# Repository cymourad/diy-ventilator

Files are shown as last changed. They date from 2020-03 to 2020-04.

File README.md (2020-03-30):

# DIY-Ventilator
This is an attempt to make a simple DIY Ventilator using:
1. Standard mask, tube, and 2 Y-pieces;
2. 3D printer and filament;
3. Arduino board, BLE module and humidity sensor;
4. Choice of battery that outputs ## V and has capacity of ##;
5. Brushless DC motor blower;
6. Oxygen tank, flow meter and regulator; and
7. HEPA filters

## Files in the Respistory
This respository contains 7 sub-repositories:
1. **app**: This respository hosts the source code of two identical mobile applications (IOS and Android) to control and monitor the ventilator.
2. **fw** (FirmWare): This directory contains the firmware code that would run on the Arduino board to control the ventilator.
3. **mech** (Mechanical): This directory contains the CAD files used to 3D print the custom parts of the ventilator, and the readily-avialble parts we bought.
4. **prototypes**: This directory is a sandbox for the team to share their early-stage design ideas, sketches, prototypes, etc.
5. **resources**: This directory contains all the references we used, as well as datasheets and manuals for readily-available parts that we used to build the ventilator.
6. **tests**: This directory includes User Acceptance Tests (UAT) to run on the assembled ventilator before the aptient uses it. It also includes tests to be run by the team as we develop the ventilator to make sure our changes are moving in the right direction.
7. **tutorials**: This directory includes the tutroials that the app will feature to educate operators on the assembly and use of the ventilator.

## Team
I am by no means working on this project alone. The team who is contributing to this project with different capacities, according to their expertise, is comprised of:
* Abanoub Rizk
* Abanoub Slaib 
* Bishoy Mikhail
* Hani Zaki
* Marina Saad
* Nazmy Markos
* Nicolas Mourad
* Youhanna Iskander
* Youssed Zaki

## WARNING
**This project is by no means complete or thoroughly tested yet!**

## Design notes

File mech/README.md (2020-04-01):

# DIY-Ventialtor Mechanical Parts
This directory contains the CAD files of the parts that must be 3D-printed to make the ventilator, as well as the readily-available parts we used (and potential equivalent parts) to make the design below.
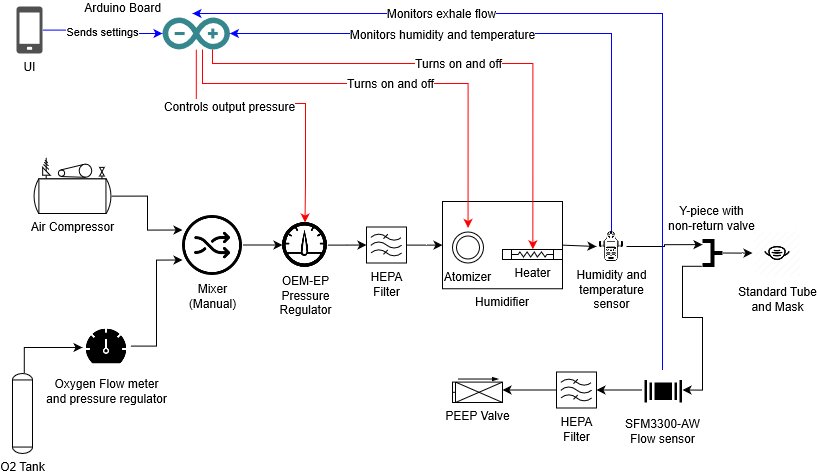
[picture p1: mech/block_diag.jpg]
Ventilator Block Diagram Design Ventilator Block Diagram


## CAD Parts

### Humidifier Chamber
* This part takes the pressure regulator output as its input and outputs to the Y-piece that connects to the tube going to the patient.
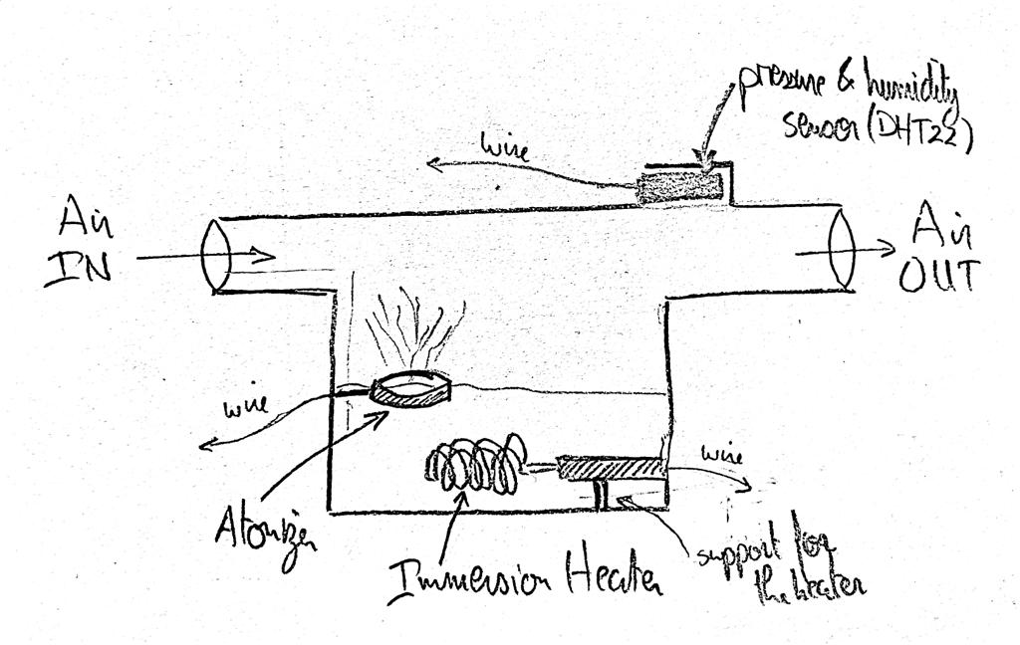
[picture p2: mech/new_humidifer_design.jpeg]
humidifer design Humidifer Design

* TODO add special instructions to print (material, orientation, printer settings )
* TODO add a picture of it printed

### HEPA Filter
* this parts makes the air pass through a HEPA filter to disinfect it
* TODO add special instructions to print (material, orientation, printer settings )
* TODO add a picture of it printed

## Readily Available Parts

### Arduino UNO Baord
* This is the brain if the ventilator, it controls the outputs and makes sense of the inputs. This is our controller.
* Can be purchased from [here](https://www.amazon.ca/ARDUINO-A000066-Uno-DIP-1-5/dp/B008GRTSV6).

### Arduino HM-10 Bluetooth Module
* This module connects to our microcontroller and it lets the user send the desired settings over bluetooth from their phone.
* Can be pruchased from[here](https://www.amazon.com/DSD-TECH-Bluetooth-iBeacon-Arduino/dp/B06WGZB2N4)

### Air Compressor
* This part is respoinsible for generating our airflow at 50 psi for belnding.
* Can be prucahsed [here](https://www.healthproductsforyou.com/p-precision-medical-easyair-pressure-compressor.html).

### Oxygen tank and oxygen regulator
* This is the source of Oxygen to regulate FiO2 higer than 21%. The regulator controls the pressure going out of the compressed oxygen tank to (typically) 3-5 bar. While
* These parts can be purchased or rented. They are standard parts so any combination should work. An example of the flow meter and regulator can be found [here](https://www.emrn.ca/en/respiratory/oxygen-regulators/o-two-oxygen-regulator-0-25-lpm-all-brass.html).

### Oxygen/Air Blender
* Regulates the pressures of the air and oxygen and lets the user control their flows to achieve desired FiO2.
* Can be purchased [here](https://www.tristatebiomedical.com/store/p160/Maxtec_MaxFLO2_Mini_Air_%2F_Oxygen_Mixer.html).

### HEPA Paper
* This piece disinfects the air before going into the machine and eventually to the patient.
* Can be purchased [here](https://www.cpap.com/productSearch#::::HEPA%20filters).

### Pressure Reducing Valve
* This piece takes the pressure down from 50 psi to 50 cmH2O for the pressure regulator to be able to reduce it to the desired range (will go down from 50 psi to 2 psi).
* Can be purchase at [here](https://www.pneumaticplus.com/pneumaticplus-ppr2-n02bg-miniature-air-pressure-regulator-1-4-npt-with-embedded-gauge-bracket/).

### Parker OEM-EP (Miniature Electronic Pressure Controller)
* This device takes any pressure greter than 40 cmH2O (can be variable pressure) and outputs a regulated pressure (10% - 100% of its input pressure.)
* Its data sheet can be found [here](https://www.parker.com/Literature/Precision%20Fluidics/Electronic%20Pressure%20Controllers/PPF_Pressure_Control_Catalog.pdf).

### Atomizer
* This small device floats on a water surface and atomizes tiny water dropplets to the air above to increase its humidity.
* Can be purchased [here](https://www.amazon.com/Gikfun-Ultrasonic-Ceramics-Sealing-Diffuser/dp/B075CHT2HY).

### Immersion heater
* Immersion heaters are commonly used to heat up water or coffe in a glass. So, we can use one to heat up the water and thus heat up to the air to reach 50 degress Celsius.
* Can be purchased [here](https://www.bedbathandbeyond.ca/store/product/portable-immersion-heater/1011091717?product_id=11091717CA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).

### Pressure and humidity sensor
* This device outputs the current temperature and relative humidity to the Arduino.
* Can be purchased [here](https://www.amazon.com/AZDelivery-Digital-Temperature-Humidity-Raspberry/dp/B07F86WXR7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).

### Y-piece with non-return valve
* This piece conncects the air flow coming from the machine with the tube, and lets the air exhaled back from the patient exit from a third outlet.
* Can be purchased [here](https://www.biodex.com/nuclear-medicine/products/lung-ventilation-systems/xenon-disposables/y-connector).

### Proximal Flow Sensor (Sensirion SFM3300-AW)
* This device reads the current flow rate. Two will be used to monitor the exhaled tidal volume.
* Its data sheet can be found [here](https://www.sensirion.com/fileadmin/user_upload/customers/sensirion/Dokumente/5_Mass_Flow_Meters/Datasheets/Sensirion_Mass_Flow_Meters_SFM3300_Datasheet.pdf).

### PEEP valve
* This device connects to the last Y-piece on the exhale end before the proximal flow sensor.
* can be purchase [here](https://www.emsstuff.com/disposable-universal-peep-valve/).

### Tube and Mask
* These are standard tube and mask to connect to the patient.
* An example tube can be found [here](https://cpapmachinescanada.ca/products/resmed-standard-tube-6-feet-and-9-feet?variant=49938448967) and masks are determined [based on the patient's features](https://www.oxygenconcentratorstore.com/cpap-mask-sizing-guide-and-maintenance/#).

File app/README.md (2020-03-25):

# DIY-Ventilator
This repositry hosts two sub-repositories that feature the code of two identical mobile applications: an IOS app and an Android.
The app conncets to the Arduino controlling the ventilator and features two main tabs:
1. Settings
2. Tutorials

As the machines is designed to be modualr, the user must first indicate in the settings which parts are connected:
* BPAP (base/default)
* Oxygen supply (to be connected immediately to the output of the ventilator)
* Humidifier (to be connected to the output of the ventilator before the tube)

Then, the user must indicate which mode they want to operate in (the tutorials give the user guidance on which mode to choose based on the conditions of the patient):
* Bi-PAP (patient is unconscious, cannot breathe on their own)
* C-PAP (patient is conscious but having difficulty breathing)
* Assist (difficult is back to normal brething but sometimes skips a breath)

The user must also enter the height, weight, age and sex of the patient for the machine to calculate some parameters. Moreover, the user can choose to have more manual control and enter a set pressure for the C-PAP mode or set low and high pressures (PIP and PEEP) for the Bi-PAP mode.

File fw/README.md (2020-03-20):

# DIY-Ventilator Firmware
This respository contains the firmware that runs on the Arduino board to control the ventilator and connect to the app.

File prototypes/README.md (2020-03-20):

# DIY-Ventilator Prototypes
This is a sandbox for the team to share our ideas, early designs and sketches.

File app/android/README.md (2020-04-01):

# DIY-Ventilator Android App
The app conncets to the Arduino controlling the ventilator and features two main tabs:
1. Settings
2. Tutorials

The respository that contains the code for the IOS app can be found [here](https://github.com/bishoymikhail/DIY-Ventilator-Android-Application).

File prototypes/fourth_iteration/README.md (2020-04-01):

# DIY-Ventilator 4th Iteration
I video conferenced Nazmy today for around 7 hours. This man wrecked almost everything. It's late. There is so much to document. I'll capture the most important things as much as I can.

## Parker pressure regulator
We forgot to check its flow range. Some max out at 20 L/min, which is pretty low, so might need to find different models and a different part all togheter. Also, because it scales it input pressure 10% - 100%, we must provide it with 40-50 cmH2O to get our desired range. So, we gotta do some serious pressure reduction to go from 50 psi (~3515.35 cmH2O) to 50 cmH2O (~70x). We might need to do this reduction on two stages. But good news is: this is a fixed reduction so we can use mechanical valves with no control and they should be cheaper

## Tidal volume
A call with an anathtiliologist (def spelled that wrong) informed us that for COVID-19, the patient would need a Vt of 6 mL/kg (yieldning and avg Vt of 0.426 L). Aslo, avg person is around 71 kgs. So, to caculate our flow rate (Q) range:
> Q [L/min] = Vt / (inhale period)

## Oxygen blending
Nazmy made it clear that it is better to blend at a high pressure. It also became clear after some research that most belnders (like [this Maxtec one](https://www.tristatebiomedical.com/store/p160/Maxtec_MaxFLO2_Mini_Air_%2F_Oxygen_Mixer.html)) are designed for the 40-50 psi range, which is conviently the pressure coming out of an Oxygen tank.
Omitting much discussion, we decided that using a ready made blender and an air compressor might be the sweet spot between precision and safety vs cost. The final concern we had was running this compressor on a battery for 3 hours in case power goes out. Nazmy is looking into this tonight.
Meanwhile, Hani was looking into using the venturi principle instead on a standard compressor and belnder. We will design the venturi and some seious control logic with some regulaor solenoids. This design would be so much cheaper (but maybe harder for an average person to assemble). Main problem with this design is it must supply a minimum FiO2 of 40%.
*Update*: Nazmy found [this medical grade compressor](https://www.healthproductsforyou.com/p-precision-medical-easyair-pressure-compressor.html). It should get the job (50 psi , min flow of 13 lpm, and great safety) down and it runs on only 0.2 hp (so we can run it on a battery for 3 hours).

## Humidifier
Also giving the summary of long dicussions here. Using a simple atomizer will not give us enough control over humidity. We generally want 55% humidity. I looked into HMEs because they seem easy and cheap.
*Update*: Even tho HMEs seem like an easy fix, they can only last for a few hours. It turns out they are usually used in surgeries. I think we can build our humidifer and test it. If it does not work as expected, we can have HMEs as plan B and pray the users will have access to them.

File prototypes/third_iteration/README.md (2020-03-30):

# DIY-Ventilator 3rd Iteration
We met again on March 28, 2020. 

## Humidifier
After studying humidifiers for the day, we learnt the following:
* there are two types of humidifiers: atomizers and heaters. Atomizers keep the temperature of the water the same and simply atomizes some water int dropplets in the air. A heater heats up the water till it evaporizes.
* temperature of air drops significantly across the tube. So industry either uses a tube that has a heater in it, or regulates the air temperature to 50 degress Celsius so that by the time it travels the standard length tube it arrives to the patient at 37 degress Celsius.

Upon some discussions around the trade-offs between accuracy, cost, availabilty of material and ease of making, we arrived to the following design.
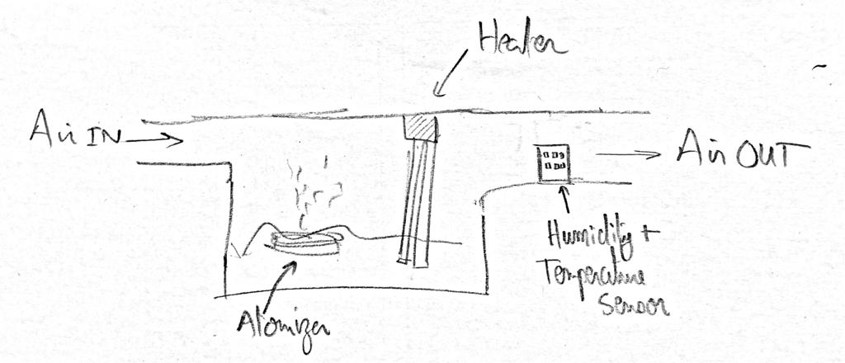
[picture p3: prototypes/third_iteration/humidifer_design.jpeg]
humidifer design Humidifer Design


An atomizer (like [this one](https://www.amazon.com/Gikfun-Ultrasonic-Ceramics-Sealing-Diffuser/dp/B075CHT2HY)) is primairly responsible for controlling the humidity level. An immersion heater (like [this one](https://www.walmart.ca/en/ip/Portable-Safe-Car-12V-24V-Immersion-Water-Heater-Auto-Electric-Tea-Coffee-Water-Heater/5EUK9APPV4YD)) is primairly responsible for heating the air to 50 degrees Celsius and it also heats up the water so it will affect the humidity slightly. A humidity and temperature sensor (like the [DHT22](https://www.amazon.com/AZDelivery-Digital-Temperature-Humidity-Raspberry/dp/B07F86WXR7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)) will provide feedback to adjust both the temperature and humidity.

## Blending Oxygen and Air
Upon his research, John generated the table below to adjust the flow rate coming out of the fan blower and the flow coming out of an oxygen tank to achieve the desired FiO2.
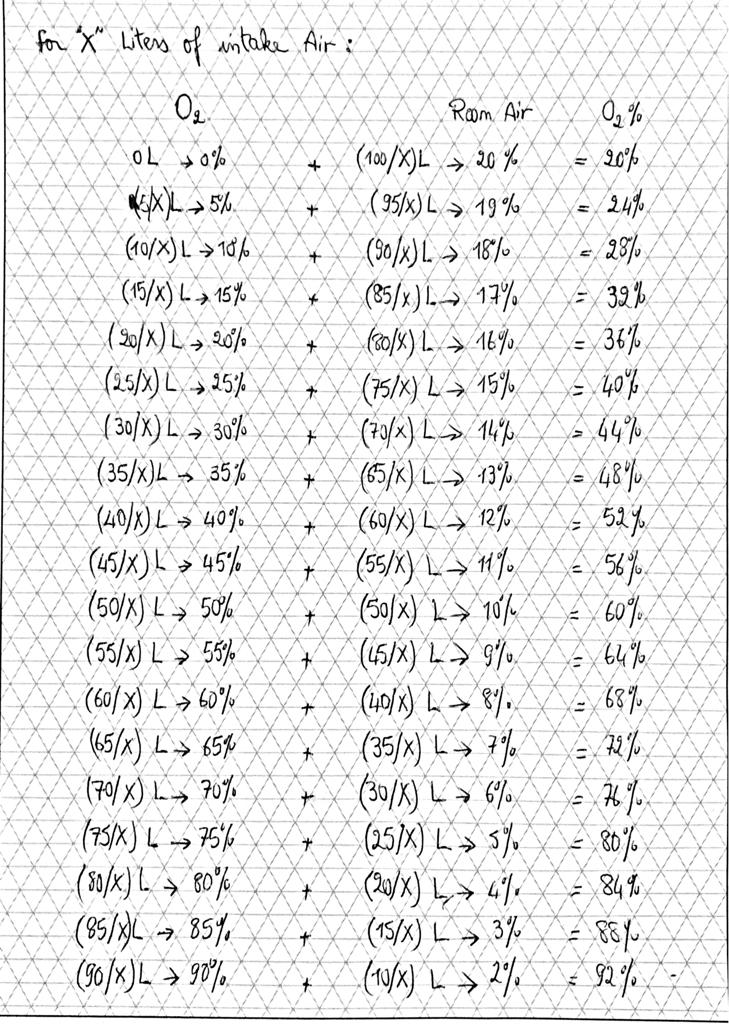
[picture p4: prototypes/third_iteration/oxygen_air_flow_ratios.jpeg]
Oxygen Blending Ratios Table


To simplify the design, the UI can tell the user to adjust the oxygen flow and pressure regulator manually (like [this one](https://www.ocelco.com/store/pc/Regulator-for-Oxygen-Flowmeter-with-1-2-15-LPM-CGA-540-Nut-and-Nipple-Inlet-Connection-p6442.htm)). These regulators and flow meters usually come with a rented oxygen tank, and they follow standards so any tank and regulator that a user chooses should work with our design. As for the flow rate of the air, it can be controlled through the speed of the fan blower. 
The control software would know what speed the fan is rotating at and this how much airflow it's generating. Thus, if we put a proximal flow sensor to meausure the combined air and oxygen flow after the y-piece, we would know the oxygen's flow rate (by substracting the fan's flow rate from the sensor's reading). Then, we can decrease or increase the speed of the fan to compnesate for any inacuracy and deliver a steady flow rate.
The design would look as follows:
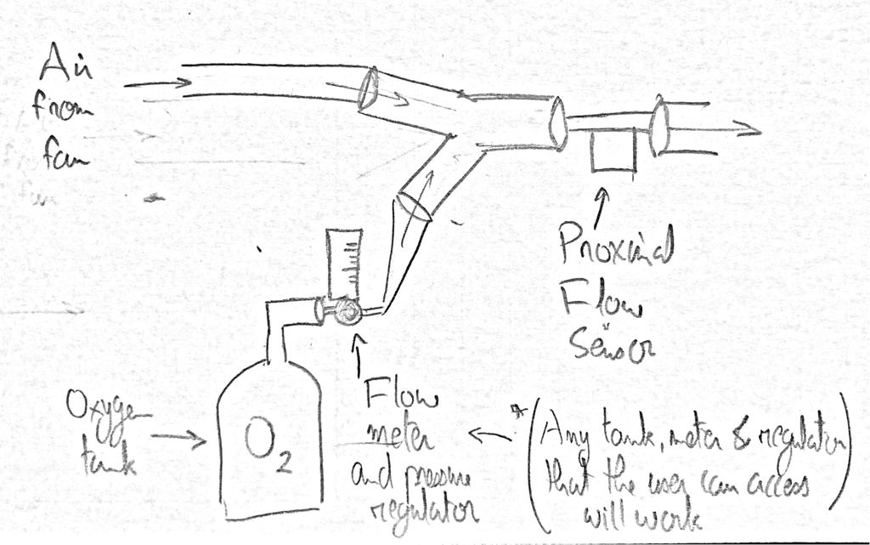
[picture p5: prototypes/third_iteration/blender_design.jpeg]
Blender Design


~~On a seperate note, if we use a delta fan blower (like [this one](https://www.digikey.ca/product-detail/en/delta-electronics/ASB0312HA-AF00/603-1723-ND/3444171) for example), we can use its [PWM signal](https://www.delta-fan.com/NewsDetail.aspx?NID=71) to control its speed and thus its flow rate. This would also mean that we would have to design our own shell to boost the fan's pressure.~~

## Pressure Control
Upon inspecting the [datasheet of the pressure regulator](https://www.parker.com/Literature/Precision%20Fluidics/Electronic%20Pressure%20Controllers/PPF_Pressure_Control_Catalog.pdf), we learnt that it can output 10-100% of the pressure that is given to it. In other words, we must provide it with a minimum of 40 cmH2O to be able to get the full range of desired pressures (5-40 cmH2O). This discovery lauched us on a quest of fluid mechanics search, we looked into using a diffuser to amplify the pressure of the fan, and looked into the equations that would help us design it. Then, we thought to find fan blowers that would simply give us the desired perssure, and we found this very reasonbaly-priced [burshless DC motor blower](https://www.alibaba.com/product-detail/12-24V-brushless-dc-motor-blower_60657146534.html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) that would deliver our desired pressure and flow rate.

This motor blower comes with a shell to amplify pressures (just like the leaf-blowers). The realtion between the airflow and the pressure it provides is shown in the following graph.
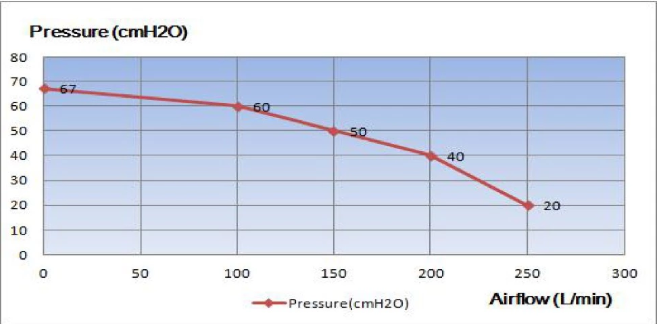
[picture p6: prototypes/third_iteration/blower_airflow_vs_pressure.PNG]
Blower's Airflow vs Pressure
.

This graph means that we can deliver up to 200 L/min and still get the required 40 cmH2O. We only to deliver 60-120 L/min, so we can definetely use this fan.

The next challenge we faced is that oxygen tanks usually deliver pressure between 3 and 5 bars, which is 3000 to 5000 cmH2O. So, tommorw, we need to find a way to bring this pressure down signiicatly to the 40 cmH2O range that the blower is gonna provide to be able to blend them with the flow rate rations in the table that John generated.

## Tidal Volume (Vt)
Our ventilator will be monitoring the exhaled tidal volme and will give the operator an alert if the user is exhaling substantially more or less volume (let's say a +/- 10% window). The standard equation to calculate tidal volume for adults is calculated based on the patient's weight (in kgs) as follows: 
> Vt = 7 mL/kg

Thus, the operator will input the patient's weight into the UI and the app will calculate the desired Vt and send it to the Arduino. If the proximal sensor indicates that the exhaled Vt is more than 10% of this reference value, or less than 10% of it, it will gove the operator an alert.

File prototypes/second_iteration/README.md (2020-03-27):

# DIY-Ventilator 2nd Iteration

Late at night on March 24, 2020, Hani, John and I had a conversation about the design. We came up with a few improvements:
* globe or butterfly valves seem like good options to control the pressure of the air and the FiO2 (they are rotary so they allow fast control, and they allow flow regulations (not just one/off))
* remembering to go back to the basics when it comes to controls, we need to now the tidal volume and the respiratory rate. Based on those 2 pieces of information we will know the volume of air that the blower must deliver. We also need to derive how long an inhale takes and how long an exhale takes (exhale takes longer) to know how often to change the pressure in Bi-PAP mode
* for Bi-PAP mode, instead of having one channel for the air and keep switching the position of the valve to change the pressure for PIP and PEEP, have a air blown by the fam split throug a y-piece that has two valves connected to its two outlets and a switch that controls which outlet the air goes to. This way, the regulating valves will only need to change their positions when settings chnage, and the switch will do the heavy lifting. This Y-piece then connect to another Y-piece to connect to the patient's tube. This would look like something similar to the picture below.
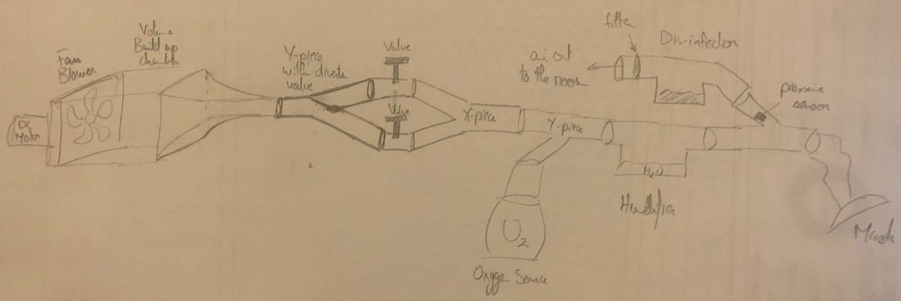
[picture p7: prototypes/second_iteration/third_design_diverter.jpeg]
third design with blower fan and 2 valves Third design with blower fan and 2 valves


Action list for our meeting on March 25, 2020:
* finalize design
* order parts and decide which parts will be designed in-house
* figure out the parameters needed to run in Bi-PAP and C-PAP modes (what we should ask the user to provide) and how to translate them into:
1. speed of fan blower, 
2. position of pressure valves, and 
3. delays when diverting flow between PIP and PEEP.

I think the diagram below might help us with this third task.
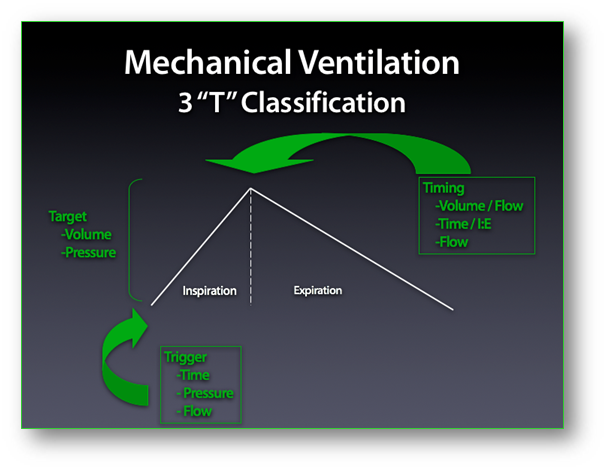
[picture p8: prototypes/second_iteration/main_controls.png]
main Bi-PAP ventilation controls Main Bi-PAP Ventilation Controls


We meet on March 25, 2020. We started by reviewing the new list of requirements one last time before changing our design and desciding what parts to buy and what parts to make. The new requirements explicitly ask for:
* the integration of a humidifier (to control humidity and air temperature), 
* the interation of an Oxygen blender (to control the FiO2),
* pressure controlled ventialtion (as opposed to volume controlled),
* A/C (Assited/Controlled breaths) modes of ventilation (a.k.a. patient-triggered vs machine-triggered ventilation), 
* monitoring of Vt (tidal volume), and
* alerts when max inhale and exhale pressures are exceeded, as well as a fail-safe method to limit the max pressure.

Those new requirements meant that the following inputs must be supplied by the user (and therefore the interface must allow the user to set them):
* PIP (Peak Inspiratory Pressure [cmH2O], 5 < PIP < 40)
* PEEP (Positive End of Exhalation Pressure [cmH2O], 4 < PEEP < 20)
* RR (Respiratory rate [breaths/minute] 4 < RR < 60)
* I:E Ratio (Ratio of Inhale to Exhale time)
* FiO2 (Perecentage of Oxygen in air [%], 20 < FiO2 < 100)
* Humidity (of air [units])
* Temperature (of air [degrees Celsius])

The machine must control:
* two pressures (PIP and PEEP),
* the intervals of switching between them,
* blending the air and Oxygen,
* humidity and temperature, and
* listening to the patient asing for a breath in patient-triggered mode.

Thus, the design we can come up with the night before seemed to satisfy the requirements. It seemed like blending should have happened before controlling the pressure and upon looking at literature it turned out that this new suggestion was true.

At this point, it was time to browse the internet to find:
* low pressure regulators (a.k.a. low pressure valves) --> for 0 to 50 cmH20 (which is 0 to 0.5 psi)
* flow meters
* oxygen blender
* fan blower
* simple humidifier

This 3 hour component search was eye-opening to say the least.
* Oxygen belnders turned out to cost somewhere between $1,000 and $2,000. Upon some literature reading, we came to the conclusion that the sweet spot of most cost effective and easy to build blender can be achieved if we just buy a flow regulator to hook up to the oxygen source, and buy a flow meter. Then, we connect those Oxygen source and the air coming out of the fan blower to a mixing chamber that we design and 3D print. When the user requests a certain FiO2, we ask them to turn the manual knob of the Oxygen flow regulator, and use the flow meter to regulate the speed of the fan blower to produce a flow of air that summed with the flow of Oxygen would result in the desired combination.
* Even though high pressure regulator are so widely available, it is considerbaly more dificult to find a low pressure regulator (for the range we are seeking to control). The next best option is a needle valve to regulate the flow (and use a pressure sensor and a feedback loop to adjust the valve to achieve desire pressure); but needle valves turned out to be not that much better in terms of avilability. Giving in to the $150 price range, we found that Parker sells a low pressure regulator that hits our desired pressure range with high accuracy and can switch between pressures fairly quickly. Thus, we decided that if $150 could give us fast switching between pressures (thus eliminatin the need for a diverter and two different channels) and precise pressure regulation (eliminating the need for two needle valves, two pressure sensors and two feedback control loops), a Parker pressure regulator (like [this one](https://www.parker.com/Literature/Precision%20Fluidics/Electronic%20Pressure%20Controllers/PPF_Pressure_Control_Catalog.pdf)) would be worth the price (especially given the time and resource constraints).
* We need a flow sensor to regulate the oxygen/air blending, and we need another one to monitor the actualy tidal valume from the exhale. Water flow meters/sensors are so widely avaibale. But, a lot of them are mechanical and thus useless to out controller, and the ones that are electronic are not suitable for air flow measurements. Instead, the type of flow sensor we are looking for is called a prximal flow sensor. An avergae prximal sensor (like [this one](https://www.sensirion.com/en/flow-sensors/proximal-flow-sensors/)) would cose around $300. 
* These parts are not usually found on Amazon or E-Bay. They even sometimes ask you to request a quote.

In light of these decisions, the final design has been modified to look as follows:
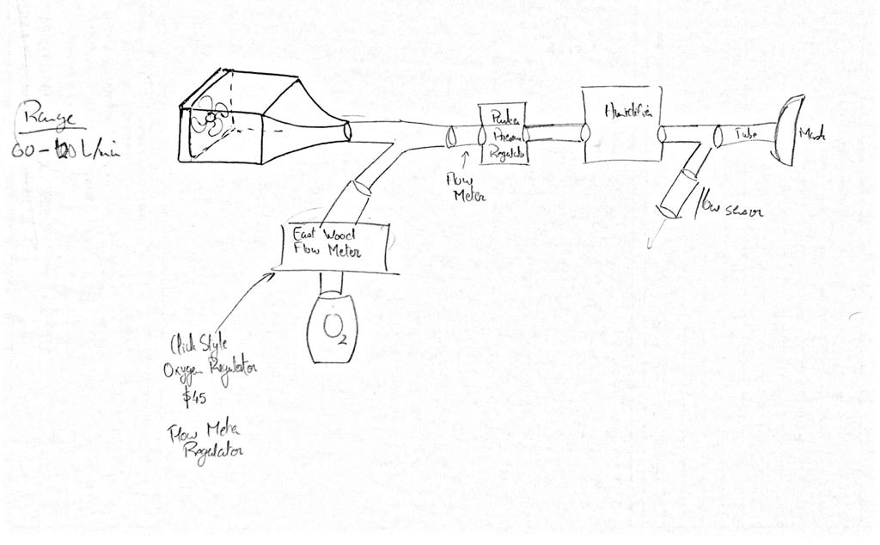
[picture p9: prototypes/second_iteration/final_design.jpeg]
final design Final Design


Final action plan:
* change interface (app) to prompt for the fina list of inputs,
* look at the data sheets of the parts we found and figure out who they will be integrated with the contoller,
* design the parts that will connect the bought parts together, and
* write the control algorithm.

### Humidifer
Arduino provides a few humidity and temperature sensors like the [DHT22](https://www.tutorialspoint.com/arduino/arduino_humidity_sensor.htm) which measures relative humidity and temperature. It as cheap as [$5](https://www.amazon.com/AZDelivery-Digital-Temperature-Humidity-Raspberry/dp/B07F86WXR7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) and it prvides reasonable accuracy for the application.
We could use one of those [mist makers](https://www.aliexpress.com/item/32986565997.html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) to vaporize water and increase humidity but if we do so we won't be able to control the temperature.
To heat the water, we can use a [commercial immersion heater](https://www.aliexpress.com/item/4000311044016.html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) and do some surgey one the wires to turn it ON/OFF with the Arduino.

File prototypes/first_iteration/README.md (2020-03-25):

# DIY-Ventialtor 1st Iteration
On March 21, 2020, Hany Zaki, Youssef Zaki, Youhanna Iskander, Nicolas Mourad and I dicussed a few ideas for a first design.

## Basic ventilator types
Hany explained to us that the early ventilators he worked with had three main modes which relate to the patient's condition:
1. **Bi-PAP**: patient is unconcscious and in very difficult condition, patiet cannot breathe on their own, Bi-PAP must artifically inhale (at Inspiratory Pressure, PIP) and exhale (at Expiratory Pressure, PEEP) at a set respiratory rate for the patient who exerts no resistance on the machine. This pressured air is often mixed with a hihger concentration of oxyen.
2. **C-PAP**: when the patient gets a little better and they become conscious and in control of their respiratory system again, the ventilator supplies constant pressured air (often mixed with oxygen).
3. **Patient-triggered**: the patient can fully brethe on thier own anf they are about to get weaned off the ventialtor but they sometimes miss a breath and/or they need a supply of oxygen, ventilator supplies pressured air at a low pressure (close to 4 cmH2O) and senses when the patient skips a breath, in which case it supplues a single IPAP cycle at the patient's average respiratory rate with their average tidal volume.

## Design principles
Common themes that we decided to kee through our design cycles were:
* break it to modules: break ventilator down to smaller standalone pieces (in case people do not need some functionalty or cannot find certain components AND for ease of testing)
* do not re-invent the wheel: use as many readily-available parts and technology as possible to increase reliability and to have online support community that can help with development and testing
* keep it simple: do not include functionality, features, or components that are not needed for most users (to minimize modes of failures and for ease of assembly and use)

## First design
We quickly came up with this first design, that was dismissed after for being a tad too complex.
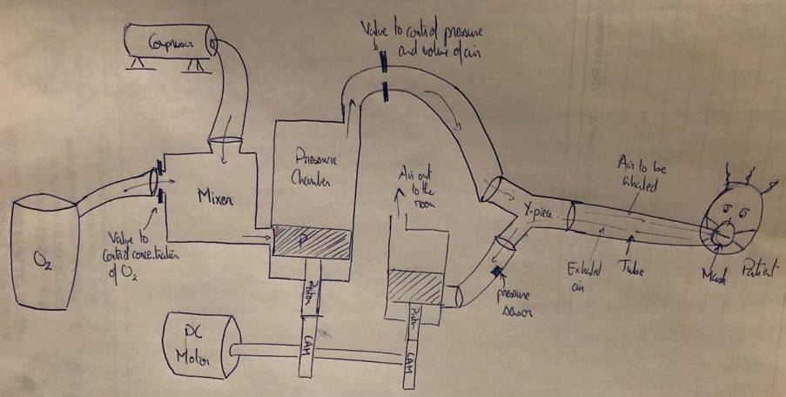
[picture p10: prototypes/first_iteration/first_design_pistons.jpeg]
first design with pistons, cam-shaft, mixer chamber, and two pressure chambers First Design with pistons and cam-shafts and mixer

Starting from the right, a mixing chamber takes compressed air from a compressor and an oxyen tank or an oxyen concentrator. The FiO2 is controlled with a valve that connects the oxygen source to this mixing chamber.
Then, the air goes into a pressure chamber. A DC motor rotates a shaft and a cam that pushes a piston to compress the air in the pressure chamber and pushes it out to a valve that controls the pressure (and volume) of the air going out to the patient. Then, the valvev connects to a Y-piece that connects on one side to the tube and mask going out to the patient, and on the other side to a tube that contains a pressure sensor and connects to a pressure chamber that sucks the air back to simulate an exhale. The second pressure chamber is operated by the same DC motor and shat but a different sized cam.

## Second design
We examined the design and found some repition (compressing the air twice first with the compressor then with the piston, using two pressure chambers for inhale and exhale). Also, since the cam had a set size, it was difficult to provide two different pressures from one pressure chamber (PIP and PEEP). So, we decided to come up with another idea and compare the two.
We decided to use a blower fan and a valve to compress the air instead of the pressure chambers. This simplified our desing quite a bit as seen in the sketch below.
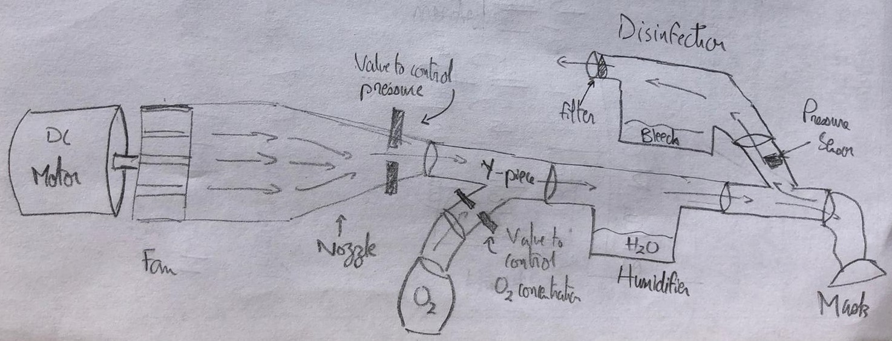
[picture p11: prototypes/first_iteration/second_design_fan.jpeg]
second design with blower fan and valve Second design with blower fan and valve

Starting from the right, a DC motor runs a blowing fan into a chamber that connects to a valve. There are a few modules that are optional to add here: a Y-piece that can let oxygen in with a valve nad/or a humidifer. Whether these modules are connected or not, a Y-piece is then connected. The Y-piece ends with a tube and a mask. The other side of the Y-piece measures the pressure of the air exhaled out of the patient and passes it through a filter before goin back to the room. It is also an option to include a disinfection unit before letting the air out.
At this point we knew that we had three things to control, and this is how this design controls them:
* **Respiratpry rate**: timer set on valve to open and close
* **Tidal volume**: speed of DC motor
* **Pressure**: how much the valve closes

### Disinfection
Nicolas was looking into ways to disinfect the exhaled air. His conclusion was that the cheapest and easiest way is to pass the exhaled air over concentrated bleech before letting it back in the room. John added that filters should be incorporated at the end of that disinfection chamber before letting the air out to keep the PH level of the room.

### Power
We decided to use a DC motor because:
* it is readily-avaible, 
* it is easy to control its speed, 
* it is easy to run it on a battery, and
* it is relatively easiser to run on AC power with readily-avaible adapters for different systems.
Upon some internet research, it seems like we might be able to use a phone charger to power the arduino and potentially a power bank as the battery as well. It will def supply the needed voltage, the question is the current. Also, seems like some chargers might not have isolation or negotiate voltage with Arduino, so must give users instructions on how to make sure the charger they use works for the Arduino.

### Volume Control
Traditionally, the datasheet of a fan blower contains a table relating angular speed to volumetric flow rate. Once we know one of these relations, we can use the equation found [here](https://www.axair-fans.co.uk/news/applications/understanding-basic-fan-laws/) to find the new speed required for the desired volumetric flow rate (this desired volumetric flow rate can be calculated from the desied tidal volume, the size of the nozzle and the respiratory rate).
As for the volume of the exhaled air, it can be calculated using pressure sensors as shown [here](https://www.sensortips.com/featured/calculate-flow-pressure-measurement/).

### Pressure Control
The valve controls the pressure going to the patient by changing the diameter of the valve. [This calculator](http://irrigation.wsu.edu/Content/Calculators/Sprinkler/Nozzle-Requirements.php) helps build intuition towards the relationship between the diameter of the nozzle (valve in our case) and the new flow rate of the water (given the initial pressure of the fluid coming in from the fan blower).

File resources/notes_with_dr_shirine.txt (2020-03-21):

for covid: they can do nothing on their own, we are gonna have a set rate

There are equations for the ventilator 
1sr level: just oxygen (no pressure)

C-pap and bipap: for consicous and moving patient

C-PAP: continuous (no oxygen in simplest form, positive pressure) --> makes pressure inside lung go higer and patient might resist it, but very easy and cheap

if oxygen is connected to cipap, we call it a ventilator

Bipap: same as cipap but makes expiration easy --> by going down to 4 cmH2O (atmospheric pressure) in intervals -> this interval is set between 14 and 16

we need a humidifer for both (has a small tank of ditilled water and is changed every couple of weeks) .. just room temperature, do not need to control temp

both ones above do not need blood work and are non-invasive

ventilator:
we have 4 settings depending on the condition of the patient
- CIMV: need xrays and samples that cannot be done at home (worst case scenario --> highest resistance possible to air coming in --> caused by collapsed/infiltrated lungs)
would need a doctor to monitor .. get other things 
- AC: assistend aor controlled ventilation 
- PSV: Pressure support ventilation
- BiPap (for weaning - make it non-invasive - oxygen would just be gping through the nose, most likely not needed)

ventilators are invasive .. so you need a professional to insert tube or else you might kill the patient

we monitor (with a different machine -- needed for everythong but bipap):
- blood pressure
- oxygen ceoncentration
- respiratpry rate
- heart rate

ventilator should monitor:
- pressure in lungs --> based on that we must 

there is an equation depending on height and weight, we decide the fllowing three controls: 
- tidal volume
- respositoary rate
- peep (pressure at end of expiration --> usually 3 cmH2O .. usuall

oxygen goes into ventialtor (you control how much oxygen goes in from the oxygen tank/condensator), then the ventilator humidifies this oxygen with air and controls its pressure and interval 

Common failure modes:
- tube slips to one lung (use stetoscope --> make sure air entry is equal bi-lateral)
- leakeage in connection (literallu go through connection manually)
- tube clog (by mucus or saliva -> use a small machine to eshfot)

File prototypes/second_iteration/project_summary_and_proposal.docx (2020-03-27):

# DIY-Ventilator Budget

# Design and functionality

The proposed design of the ventilator is shown in Figure 1. It is a pressure-controlled ventilator that can run in both Assistive breaths and controlled breaths for invasively, and as a C-PAP or Bi-PAP non-invasively. The design uses an air blower to generate flow and then uses a flow meter and flow regulator to blend this air with Oxygen to allow the operator to control the FiO2. Then uses a low-pressure regulator to control the pressure of the air flow. The air then goes through a humidifier (also controlled by the operator where they can specify desired temperature and humidity. The humidifier uses a commercial water heater and a humidity/pressure. The air is connected to a Y-piece to let air go to patient and monitor the exhaled tidal volume. The air is then delivered to the patient through a standard and mask (either invasive or non-invasive).

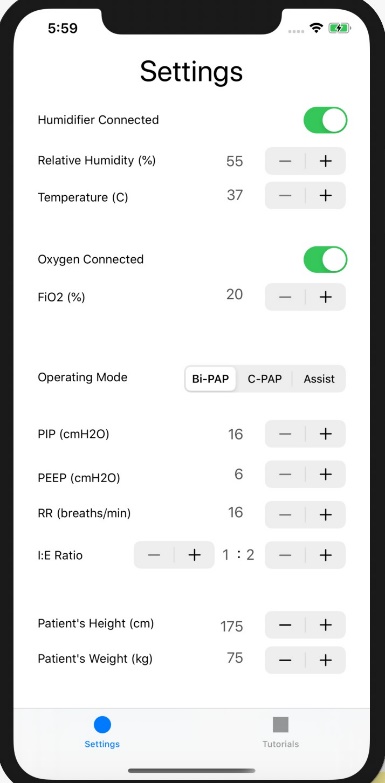
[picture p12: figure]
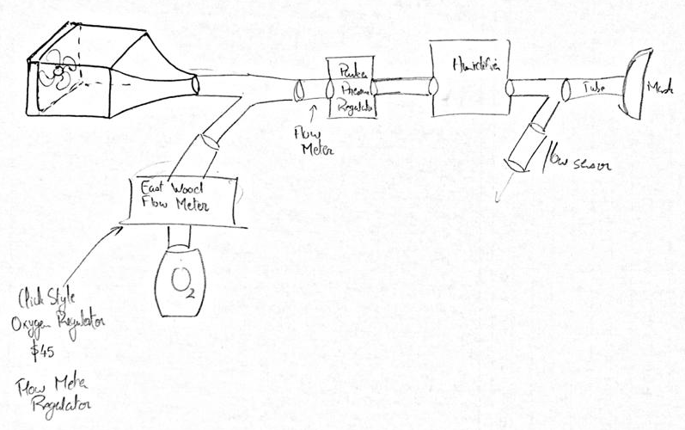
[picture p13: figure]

Figure 1: Design of Ventilator

An Arduino board controls the device and the operator uses a smartphone app to learn more about the machine and the settings, and to set the appropriate settings (as shown in Figure 2) and send them to the machine over Bluetooth.

Figure 2: Settings tab on interface

# Budget

## Parts to Buy

Table 1: Budget for the parts to be bought

Part Name | Manufacturer | Part Number | Price | Quantity Needed | Total
Low Pressure Regulator | Parker | OEM-EP | $ 150.00 | 1 | $ 150.00
Proximal Flow Sensor | Sensirion | SFM3300-AW | $ 300.00 | 2 | $ 600.00
Fan Blower | Sanyo Denki America | 9CR0612H001 | $ 45.00 | 1 | $ 45.00
Arduino Board | Arduino | UNO | $ 40.00 | 1 | $ 40.00
Bluetooth Module | DSD Tech | HM-10 | $ 12.00 | 1 | $ 12.00
Emergency Stop Button | SODIAL® | | $ 7.00 | 1 | $ 7.00
Wires + Misc | | | $ 20.00 | 1 | $ 20.00
Humidity/Temperature Sensor | AZDelivery | DHT22 | $ 6.00 | 1 | $ 6.00
Immersion Heater | Graigner | WWG2E756 | $ 8.00 | 1 | $ 8.00
Standard Mask | | | | 1 | $ -
Standard Tube | | | | 1 | $ -

## Parts to Print

Table 2: Budget for the parts to be printed

Part Name | Manufacturer | Part Number | Avg Filament Price (per kg) | Approximate Weight (kg) | Total
Pressure Chamber | you | pressure_chamber | $ 25.00 | 0.2 | 5.00
Blender Chamber | you | blender_chamber | $ 25.00 | 0.2 | $ 5.00
Humidifier Chamber | you | humidifier chamber | $ 25.00 | 0.1 | $ 2.50

## Total Budget

This totals up to $900.5.

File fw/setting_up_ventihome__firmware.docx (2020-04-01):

# Setting up the firmware

1. Download Arduino IDE (https://www.arduino.cc/en/main/software) and set it up.
2. Download the control sketch from (https://github.com/cymourad/diy-ventilator/blob/master/fw/control/generic_control_sketch/generic_control_sketch.ino).
3. Open the downloaded sketch with the Arduino IDE.
4. Connect to the Arduino to your computer via USB.
5. Click on the verify button at the top right.
6. Click on the upload file at the top right.

** If you never used an Arduino before, this tutorial will explain this process with pictures (https://www.arduino.cc/en/Guide/ArduinoUno).

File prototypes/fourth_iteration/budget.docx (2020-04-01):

# Parts to Buy

Part Name | Manufacturer | Part Number | Price | Quantity Needed | Total
Proximal Flow Sensor | Sensirion | SFM3300-AW | $ 300.00 | 1 | $ 300.00
Arduino Board | Arduino | UNO | $ 40.00 | 1 | $ 40.00
Bluetooth Module | DSD Tech | HM-10 | $ 12.00 | 1 | $ 12.00
Humidity/Temperature Sensor | AZDelivery | DHT22 | $ 6.00 | 1 | $ 6.00
Immersion Heater | Graigner | WWG2E756 | $ 8.00 | 1 | $ 8.00
Mask | RedMEd | Dependant on Individual | ~ $. 140 | 1 | $ 140.00
Atomizer | Gikfun | EK1868 | $ 9.00 | 1 | $ 9.00
PEEP Valve | AMBU | D4-177 | $ 10.00 | 1 | $ 10.00
Air Compressor | Precision Medical Inc. | PM 15 | $ 550.00 | 1 | $ 550.00
Oxygen Regulator | O-Two | 01RO01003-B | $ 10.00 | 1 | $ 110.00
Oxygen/Air Blender | Maxtec | R223P08 | $ 300.00 | 1 | $ 300.00
Tube | RedMed | 14999 | $ 20.00 | 1 | $ 20.00
HEPA Filter Paper | Generic | AG36855-6-CDCPF | $ 12.00 | 1 | $ 12.00
Pressure Reducing Valve | Pneumatic Plus | PPR2-N02BG | $ 30.00 | 1 | $ 30.00
Pressure OEM-EP | Parker | | $ 150.00 | 1 | $ 150.00
Y-Piece and Non-return Valve | RICO SUCTION LABS | 2048P | $ 15.00 | 1 | $ 15.00

# Parts to 3D-print

Part Name | Manufacturer | Part Number | Avg Filament Price (per kg) | Approximate Weight (kg) | Quantity | Total
Humidifier Chamber | User | N/A | $ 25.00 | 0.1 | 1 | $ 2.50
HEPA Filter Chamber | User | N/A | $ 25.00 | 0.2 | 2 | $ 5.00

# Total budget

$ 1,712.00

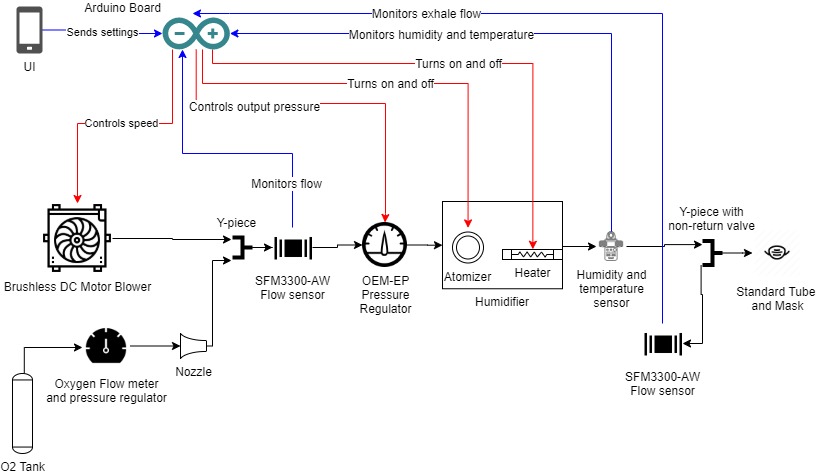
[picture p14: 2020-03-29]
mech/blower_block_diag.jpg

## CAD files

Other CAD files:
mech/HEPA_input_chamber.ipt
mech/HEPA_nut.ipt
mech/HEPA_output_chamber.ipt
mech/humidifier_adapter.ipt
mech/humidifier_chamber.ipt
mech/humidifier_cover.ipt

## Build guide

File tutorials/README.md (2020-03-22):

# DIY-Ventilator Tutorials
These tutorials go on the app and teach the operator to:
1. Assemble and set-up the ventilator,
2. Test the ventilator,
3. Configure the different settings of the machine, and
4. Stop the machine in case of emergency.

Moreover, there are some tutorials tailored for education:
* difference between the diff operation modes (Bi-PAP, C-PAP, Assist) and when the patient needs each one.
* etc.

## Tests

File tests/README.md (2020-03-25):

# DIY-Ventilator Tests
These are some basic test cases to run the ventilator through once you assemble it and before you let a patient use it.
You can also run them whenever you want.
** All the tests assume that all the parts of the ventilator are assembled correctly.

## User Acceptance Tests

### User Acceptance Test 1
##### Settings
| Setting | Configuration |
|---|---|
| Setting 1 | Configuration 1 |
| Setting 2 | Configuration 2 |
| Setting 3 | Configuration 3 |
##### Expected Ventilator Behavior
Describe what the behavior would look/sound like (ex:high noise, low noise, if you put your hand at the tube you would feel presure, etc).
Might also wanna explain when these settings would be applied (the condition of the patient that requires these settings), and maybe how these settings would help the patient.
##### How to Meausre the Success of the Test
Describe the sesnors/mechanisms needed to ensure the ventilator behaves as expected.

### User Acceptance Test 2
##### Settings
| Setting | Configuration |
|---|---|
| Setting 1 | Configuration 1 |
| Setting 2 | Configuration 2 |
| Setting 3 | Configuration 3 |
##### Expected Ventilator Behavior
Describe what the behavior would look/sound like (ex:high noise, low noise, if you put your hand at the tube you would feel presure, etc).
Might also wanna explain when these settings would be applied (the condition of the patient that requires these settings), and maybe how these settings would help the patient.
##### How to Meausre the Success of the Test
Describe the sesnors/mechanisms needed to ensure the ventilator behaves as expected.

### User Acceptance Test 3
##### Settings
| Setting | Configuration |
|---|---|
| Setting 1 | Configuration 1 |
| Setting 2 | Configuration 2 |
| Setting 3 | Configuration 3 |
##### Expected Ventilator Behavior
Describe what the behavior would look/sound like (ex:high noise, low noise, if you put your hand at the tube you would feel presure, etc).
Might also wanna explain when these settings would be applied (the condition of the patient that requires these settings), and maybe how these settings would help the patient.
##### How to Meausre the Success of the Test
Describe the sesnors/mechanisms needed to ensure the ventilator behaves as expected.

## Engineering Tests
The following tests were used when developing the machine and we encourage anyone who decides to fork this design to run them when they make modifications. We would also encourage all developers and health professionals to add other tests as they see fit, or reach out to us to add them.

### Engineering Test 1 - Min PIP and min PIP
##### Settings
| Setting | Configuration |
|---|---|
| Mode | Bi-PAP |
| PIP | 10 cmH2O |
| PEEP | 4 cmH2O |
##### Expected Ventilator Behavior
The ventilator can supply the minimum inspiratory pressure and the minimum expiratory pressure.
##### How to Meausre the Success of the Test
Connect mask to pressure sensor to measure inspiratory pressure and use the sensor at the Y-piece to meausre the epiratory pressure.

### Engineering Test 2 - Max PIP and max PEEP
##### Settings
| Setting | Configuration |
|---|---|
| Mode | Bi-PAP |
| PIP | 40 cmH2O |
| PEEP | 20 cmH2O |
##### Expected Ventilator Behavior
The ventilator can supply the maximum inspiratory pressure and the maximum expiratory pressure.
##### How to Meausre the Success of the Test
Connect mask to pressure sensor to measure inspiratory pressure and use the sensor at the Y-piece to meausre the epiratory pressure.

### Engineering Test 3 - Max PIP and min PEEP
##### Settings
| Setting | Configuration |
|---|---|
| Mode | Bi-PAP |
| PIP | 40 cmH2O |
| PEEP | 4 cmH2O |
##### Expected Ventilator Behavior
The ventilator can supply the maximum inspiratory pressure and the minimum expiratory pressure.
##### How to Meausre the Success of the Test
Connect mask to pressure sensor to measure inspiratory pressure and use the sensor at the Y-piece to meausre the epiratory pressure.

### Engineering Test 4 - Min PIP and max PEEP
##### Settings
| Setting | Configuration |
|---|---|
| Mode | Bi-PAP |
| PIP | 10 cmH2O |
| PEEP | 20 cmH2O |
##### Expected Ventilator Behavior
The ventilator cannot supply an inspiratory pressure that is higher than the expiratory pressure.
##### How to Meausre the Success of the Test
Ventilator errors out.

### Engineering Test 5 - Avergae Bi-PAP Pressures
##### Settings
| Setting | Configuration |
|---|---|
| Mode | Bi-PAP |
| PIP | 20 cmH2O |
| PEEP | 8 cmH2O |
##### Expected Ventilator Behavior
The ventilator can supply an average inspiratory pressure and an average expiratory pressure.
##### How to Meausre the Success of the Test
Connect mask to pressure sensor to measure inspiratory pressure and use the sensor at the Y-piece to meausre the epiratory pressure.

### Engineering Test 6 - Max C-PAP Pressure
##### Settings
| Setting | Configuration |
|---|---|
| Mode | C-PAP |
| Pressure | 40 cmH2O |
##### Expected Ventilator Behavior
The ventilator can supply the maximum pressure in C-PAP mode.
##### How to Meausre the Success of the Test
Connect mask to pressure sensor to measure inspiratory pressure.

### Engineering Test 7 - Min C-PAP Pressure
##### Settings
| Setting | Configuration |
|---|---|
| Mode | C-PAP |
| Pressure | 6 cmH2O |
##### Expected Ventilator Behavior
The ventilator can supply the minimum pressure in C-PAP mode.
##### How to Meausre the Success of the Test
Connect mask to pressure sensor to measure inspiratory pressure.

### Engineering Test 8 - Above-max C-PAP Pressure Error
##### Settings
| Setting | Configuration |
|---|---|
| Mode | C-PAP |
| Pressure | 50 cmH2O |
##### Expected Ventilator Behavior
The ventilator signals an error when requested to supply pressure that's higher than the approved average.
##### How to Meausre the Success of the Test
Connect mask to pressure sensor to measure inspiratory pressure, notthing should happen.

### Engineering Test 9 - Patient-effort Triggered
##### Settings
| Setting | Configuration |
|---|---|
| Mode | Spontaneous |
##### Expected Ventilator Behavior
The ventilator recognizes a skipped breath and compensates for it with an inspiration that has the average respiratory rate, tidal volume, and inspiratory pressure of the patient over the past hour.
##### How to Meausre the Success of the Test
Connect mask to pressure sensor to measure inspiratory pressure.

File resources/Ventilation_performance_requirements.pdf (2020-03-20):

VENTILATION PERFORMANCE

1. Pressure controlled
1. Inspiratory pressure up to 40cmH2O
2. Expiratory pressure up to 20cm H2O
3. Respiratory rate from 5-40 breaths a minute
4. Measurement of tidal volume at the Y piece
2. FiO2 from 20% to 100% in discreet steps of 10%
3. Triggering—timed or patient-effort triggered
4. Connect to standard masks and tubes
5. Connect to standard oxygen connectors
6. Accuracy (<10% for volumes and pressure, to 1 breath a minute for rate
7. Can work on internal battery for >180 min
8. Oxygen concentration NOT mandatory, recommended

PATIENT SAFETY
ALARMS OR LIMITS
1. Minute Ventilation (low/High) alarm
2. Peak pressure, Low expiratory pressure and/or disconnection alarm
3. Low expiratory pressure
4. Oxygen concentration
5. Non-rebreathing valves
DEVICE SAFETY
1. Electrical safety requirements
2. Fire safety (i.e., pure O2 flowing) INFECTION CONTROL
1. HEPA filtered inlet and outlet
2. Easy-to-clean surfaces
DESIGN REQUIREMENTS
USER INTERACTION
1. Simple to use--must not require specialized training
2. Modular, with known failure potential for each component
3. Easy to maintain (related to modularity)
4. Settings legible from 1m
5. Clear flow directions
MATERIAL AND MANUFACTURABILITY
1. Widely available material (e.g. 3D printable filaments, plastic/metal sheets)
2. Can be built locally using either simple tools or rapid prototyping (i.e. 3D printing, CNC, etc.)
3. Only eligible material allowed (see list to exclude)
OPERATIONAL REQUIREMENTS
1. Both 110V and 220V
TESTING, CALIBRATION, AND MAINTENANCE REQUIREMENTS
1. Tests to calibrate and validate volume and pressure settings
2. Tests to verify limits and alarms
3. Illustrated and clear diagram for taking apart, replacing, and rebuilding the device safely

REFERENCES
1. ISO 80601-2-12:2020 Standard for Medical electrical equipment — Part 2-12: Particular requirements for basic safety and essential performance of critical care ventilators

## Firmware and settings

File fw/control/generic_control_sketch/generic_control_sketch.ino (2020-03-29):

#include <SoftwareSerial.h> // will allow us to use the serial communication library

// Connect the HM-10 to pins 0, 1, 5V, and Gnd and use the 1 and 2 k resistors for the Rx connection
SoftwareSerial HM10(2, 3); // RX = 2, TX = 3 on the HM-10 Module itself

// variable to store the operation instructions sent from HM10 and the app
String inData = "";

// CONSTANTS
int LED = 13; // most arduino boards have an onboard LED on pin 13 (used to identify program status)
int BAUD_RATE = 9600;
int EXHALE_PROXIMAL_FLOW_SENSOR = 1;
int INHALE_PROXIMAL_FLOW_SENSOR = 0;

// Operation variables
int FiO2 = 20; // default is 20% FiO2
int humidityLevelReference = 55; // default relative humidity is 55 [%] 
int temperatureReference = 37; // deafult air temperature 
int respiratpryRate = 16; // deafult respiratory rate is 16 [breaths/min]
int iPortion = 1; // the I in the I:E ratio
int ePortion = 2; // the E in the I:E ratio
int pip = 16; // default PIP (inspritation pressure in Bi-PAP mode) is 16 [cmH2O]
int peep = 6; // default PEEP (inspritation pressure in Bi-PAP mode) is 6 [cmH2O]

bool isHumidifying = false;

// Helper variables
String prevSettings = "";
String operationMode = "A"; // default is assist mode
double breathPeriod = 4000; // [milli-seconds/breath]
int inhalePeriod = 1000; // inhale time per breath [ms]
int exhalePeriod = 2000; // exhale time per breath [ms]
int timeToExecuteOtherCycles = 10; // time taken by cycles in loop() [ms]
int currentHumidity = 55; // the current sensor reading of the humidity
int currentTemperature = 37; // the current sensor reading of the temperature

void setup() { // called once pers startup

  Serial.begin(BAUD_RATE);
  
  Serial.println("HM10 serial started at 9600"); // debugging statement
  
  HM10.begin(BAUD_RATE); // set HM10 to the BAUD rate
  
  
  // start sequence -> flash LED 3 times
  pinMode(LED, OUTPUT); // set up pin as output
  for (int i = 0; i < 3; i++) {
    digitalWrite(LED, HIGH); // turn on LED (i.e. set to HIGH voltage)
    delay(500); // wait for 500 ms (i.e. half a second)
    digitalWrite(LED, LOW);
    delay(500);
  }
  
}

void loop() { // continuous loop

  HM10.listen(); // listen to the HM10 port

  while (HM10.available() > 0) { // if HM10 sends smth, read it
    
    inData = String(HM10.read()); // save the data to string format
    
    // change the settings only if there are new settings
    if (inData != prevSettings) {
      Serial.println("New settings!"); // for debugging
      applyNewSettings(inData);
      prevSettings = inData;
    }
    
    Serial.println(inData);
  }
    
  // ACTUAL CONTROL CODE

  // make sure humidity and temperature match the desired settings
  if (isHumidifying) {

    // TODO monitor humidity level (populate currentHumidity)
    readHumidityTemperatureSensor();

    // TODO coorect the humidity / temperature if it does not match the desired one
    if (currentHumidity != humidityLevelReference) {
      if (currentTemperature <= temperatureReference && currentHumidity < humidityLevelReference) {
        turnHeaterOn();
      }
      else if (currentTemperature >= temperatureReference && currentHumidity > humidityLevelReference) {
        turnHeaterOff();
      }
    }
  }
  
  // Mode of operation and its parameters
  if (operationMode == "B") { // Bi-PAP mode

      setPressureRegulator(pip); // TODO set the pressure regulator to the PIP
      delay(inhalePeriod); // TODO change to the exact inhale time needed 

      setPressureRegulator(peep); // TODO set the pressure regulator to the PEEP
      delay(exhalePeriod - timeToExecuteOtherCycles); // TODO change to the excat exhale time needed minus an estimate of cycles lost performing other tasks in the loop
      
      // TODO check the exhale flow meter to make sure tidal volume is good

  } else if (operationMode == "C"){ // C-PAP mode
      // There is not much to do every cycle, the pressure keeps going at same rate from one side
  } else {  // Assit Mode 
      // TODO average readings from pressure sensor to find PIP, PEEP, inhalePeriod and exhalePeriod
      // TODO listen to the pressure sensor in case patient misses a breath
      // TODO if breath missed, apply avgPIP for avgInhalePeriod
      }
}

void applyNewSettings(String inData) {
  
  // FiO2
  if (inData.charAt(1) == 1) { // O2 source is connected

      FiO2 = int(inData.charAt(2)) * 10; // FiO2 (in increments of 10)

      if (FiO2 = 10) FiO2 = 100; // dirty solution to allow 100% (by writing 1, cuz we cant have 10% anyway)

      // TODO set oxygen flow regulator to allow desired FiO2 !!manually!!
      // TODO and adjust the speed of the fan to provide appropriate total flow and FiO2


  } else if (inData.charAt(1) == 0) { // O2 is not connected
      // TODO make sure the input flow-meter reading matches the expected flow calcualted for the fan and correct it if needed
  } else { // wrong string was sent, do nothing (and flash light to indicate wrong string)
      Serial.println("Wrong settings string sent, the oxygen status must be 0 or 1!");
      failureLEDalert(5); // falsh LED 5 times to tell the user they sent faulty settings
  }

  // Humidity and temperature
  if (inData.charAt(3) == 1) { // humidifer is connected
      isHumidifying = true; // set a bool to monitor humidity
      humidityLevelReference = int(inData.charAt(4)) * 10 + int(inData.charAt(5));
      temperatureReference = int(inData.charAt(6)) * 10 + int(inData.charAt(7));
  } else if (inData.charAt(3) == 0) { // humudifier is not connected
      isHumidifying = false;
  } else { // wrong string was sent, do nothing (and flash light to indicate wrong string)
      Serial.println("Wrong settings string sent, the humidifier status must be 0 or 1!");
      failureLEDalert(5); // falsh LED 5 times to tell the user they sent faulty settings
  }

  // Mode of operation and its parameters
  if (String(inData.charAt(0)) == "B") { // Bi-PAP mode
      Serial.println("Setting ventilator to Bi-PAP mode"); // for debugging

      operationMode = "B"; // setting the operation mode

      readFourBreatingParamsFromSettingsString();

  } else if (String(inData.charAt(0)) == "C") { // C-PAP Mode
      Serial.println("Setting ventilator to C-PAP mode"); // for debugging

      operationMode = "C"; // setting the operation mode

      // get the required parameter from the control string
      int peepSent = int(inData.charAt(14)) * 10 + int(inData.charAt(15));
      if (peepSent < 4 || peepSent > 20) {
        wrongSettingStringAlert("Wrong settings string sent, the PEEP must be between 4 and 20 cmH2O!");
      } else {
        peep = peepSent;
      }

      // TODO set the PEEP valve to satisfy this constant pressure setting
      setPressureRegulator(peep);

      // TODO adjust flow in

  } else if (String(inData.charAt(0)) == "A") { // Assist mode
      Serial.println("Setting ventilator to Assist mode"); // for debugging

      operationMode = "A"; // setting the operation mode

      readFourBreatingParamsFromSettingsString();

  } else if (String(inData.charAt(0)) == "T") { // Test mode
      // TODO run test routine
      operationMode = "A"; // set to assist mode (default) when done running the tests
  } else { // wrong string was sent, do nothing (and flash light to indicate wrong string)
      wrongSettingStringAlert("Wrong settings string sent, the operation mode must be A, B, C, or T!");
  }
}

// save the 4 parameters needed to operate on Bi-PAP/Assist mode from the control string to the global variables
void readFourBreatingParamsFromSettingsString() {
  // Respiratory Rate
  int respiratpryRateSent = int(inData.charAt(8)) * 10 + int(inData.charAt(9));
  if (respiratpryRateSent < 4 || respiratpryRateSent > 60) {
    wrongSettingStringAlert("Wrong settings string sent, the respiratory rate must be between 4 and 60 breaths/min!");
  } else {
    respiratpryRate = respiratpryRateSent;
  }

  // I:E Ratio
  iPortion = int(inData.charAt(10));
  ePortion = int(inData.charAt(11));

  // PIP
  int pipSent = int(inData.charAt(12)) * 10 + int(inData.charAt(13));
  if (pipSent < 4 || pipSent > 40) {
    wrongSettingStringAlert("Wrong settings string sent, the PIP must be between 4 and 60 cmH2O!");
  } else {
    pip = pipSent;
  }

  // PEEP
  int peepSent = int(inData.charAt(14)) * 10 + int(inData.charAt(15));
  if (peepSent < 4 || peepSent > 20) {
    wrongSettingStringAlert("Wrong settings string sent, the PEEP must be between 4 and 20 cmH2O!");
  } else {
    peep = peepSent;
  }

  // calculate intervals of inhale and exhale (inhalePeriod and exhalePeriod) based on the new respiratory rate
  breathPeriod = (60 / respiratpryRate) * 1000; // [ms]
  inhalePeriod = breathPeriod * iPortion / (iPortion + ePortion); // [ms]
  exhalePeriod = breathPeriod - inhalePeriod; // [ms]
}

// can use this function to test the HM-10 Module
void testHM10() {
    if (Serial.available()) { // Read user input if available for debugging
    delay(10);
    HM10.write(Serial.read());
  }
}

// in case of a wrong settings string, output instructons to Serial (and maybe bluetooth later) and flash LED tiidicate error
void wrongSettingStringAlert(String message) {
  Serial.println(message);
  failureLEDalert(5); // falsh LED 5 times to tell the user they sent faulty settings
}

// flash LED to signal that something failed
void failureLEDalert(int seconds) {
  for (int i = seconds; i < 5; i++) {
    digitalWrite(LED, HIGH); // turn on LED (i.e. set to HIGH voltage)
    delay(500); // wait for 500 ms (i.e. half a second)
    digitalWrite(LED, LOW);
    delay(500);
  }
}

// read the humidity sensor to find realtive humidity and temp
void readHumidityTemperatureSensor() {
  // THOUGHT might need to average or compare to old values in case of noise
  currentHumidity = 100; // TODO fill this reading correctly
  currentTemperature = 90; // TODO fill this reading correctly
}

void turnHeaterOn() {
  // TODO send voltage to turn the heater ON
}

void turnHeaterOff() {
  // TODO send voltage to turn the heater OFF
}

void setPressureRegulator(int pressure) {
  // TODO send voltage to apply
}

double readFlow(int sensorNumber) {
  // TODO read value of proximal flow sensor and return it in milli-Liter per second [mL/s]
  return 5;
}

// apply appropriate voltage to fan blower to achieve desired total flow [mL/sec]
void changeFanSpeedToAchieveFlow(int desiredFlow) {
  // TODO read current flow
  double currentFlow = readFlow(INHALE_PROXIMAL_FLOW_SENSOR);
  // TODO change speed of fan till flow matches desired flow (might need to allow for some tolerance --> while(currentFlow < desiredFlow * 0.95 && currentFlow > desiredFlow * 1.05))
  while(currentFlow != desiredFlow) {
    if (currentFlow < desiredFlow) { // need to make fan go faster
      // TODO set this to an incremental speed
      setFanSpeed(10);
    } else { // need to make fan go slower
      // TODO set this to a decremental speed
      setFanSpeed(10);
    }
  }
}

void setFanSpeed(int speed) {
  // TODO apply voltage to fan to set its speed
}

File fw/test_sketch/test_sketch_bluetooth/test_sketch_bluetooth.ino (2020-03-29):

// https://circuitdigest.com/microcontroller-projects/how-to-use-arduino-and-hm-10-ble-module-to-control-led-with-android-app
// used this tutorial

#include <SoftwareSerial.h>
SoftwareSerial HM10(2, 3); // RX = 2, TX = 3
char appData;  
int inData = 5;
void setup()
{
  Serial.begin(9600);
  Serial.println("HM10 serial started at 9600");
  HM10.begin(9600); // set HM10 serial at 9600 baud rate
  pinMode(13, OUTPUT); // onboard LED
  digitalWrite(13, LOW); // switch OFF LED

}

void loop()
{
  HM10.listen();  // listen the HM10 port
  while (HM10.available() > 0) {   // if HM10 sends something then read
    Serial.println("HM-10 is available!");
    appData = HM10.read();
    inData = int(appData);  // save the data in string format
    Serial.write(appData);
  }

 
  if (Serial.available()) {           // Read user input if available.
    delay(10);
    HM10.write(Serial.read());
  }
  if ( inData == 0) {
    Serial.println("LED OFF");
    digitalWrite(13, LOW); // switch OFF LED
    delay(500);
  }
  if ( inData == 1) {
    Serial.println("LED ON");
    digitalWrite(13, HIGH); // switch OFF LED
    delay(500);
    digitalWrite(13, LOW); // switch OFF LED
    delay(500);
  }
}

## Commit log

2020-03-22 adds pistons design pic
2020-03-24 adds arduino init sketch with LED
2020-03-25 adds thir design and fixes PEEP and PIP
    [sketch_mar24_mh10.ino]
2020-03-27 adds budget and proposal
    [budget.xlsx]
2020-03-29 adds third prototype
2020-03-29 updates budget and adds bluetooth test sketch
    [budget.xlsx]
2020-03-29 updates pressure control in third iteration
2020-03-29 adds first humidifier CAD
    [Chamber.ipt]
2020-03-29 adds fan to ventilator_block_diagram.drawio
2020-03-29 adds oxygen nozzle to block diagram
2020-03-30 adds PEEP valve
2020-03-31 adds 4th iter
    [P_and_I_diagram.xlsx]
2020-04-01 adds pressure regulator to parts
2020-04-01 updates pressure reducer
2020-04-01 renames CADs
    [HEPA_input_chamber.ipt, HEPA_nut.ipt, HEPA_output_chamber.ipt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]
2020-04-01 updates budget
    [budget.xlsx]
2020-04-01 adds humidifier cover cad
    [humidifier_cover.ipt]
